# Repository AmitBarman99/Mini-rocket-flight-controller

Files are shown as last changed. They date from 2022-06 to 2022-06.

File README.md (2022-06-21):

# Mini-rocket-flight-controller
PCB board of mini rocket flight controller capable to store flight data

## The image of  this PCB board :point_down:

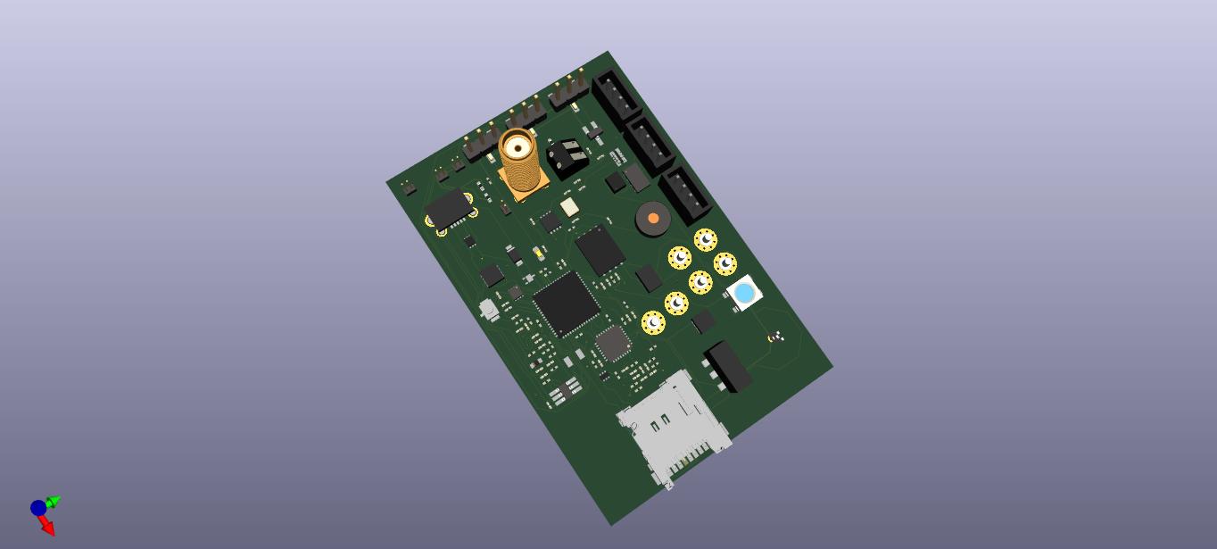
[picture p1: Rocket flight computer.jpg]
Rocket flight controller


### If you want to use this,follow these steps....

1. Download the [kicad](https://www.kicad.org/) and install it.
2. clone this repository

```bash
 git clone https://github.com/AmitBarman99/Mini-rocket-flight-controller.git 
```

3. Open the files or folder and customize them.
4. You can use [JLC pcb](https://jlcpcb.com/) for PCB fabrication

## [click here](https://amitbarman99.github.io/Mini-rocket-flight-controller/) to see the PCB board in 3D environment

 Be patient, it takes time to load
 
  I got help from this :point_right:[Repository](https://github.com/easyw/vrm360) to setup this 3D visualization. You can see it.

  ```javascript
  
  if (isAwasome){
        return true;
  }
  ```

  ## All the best

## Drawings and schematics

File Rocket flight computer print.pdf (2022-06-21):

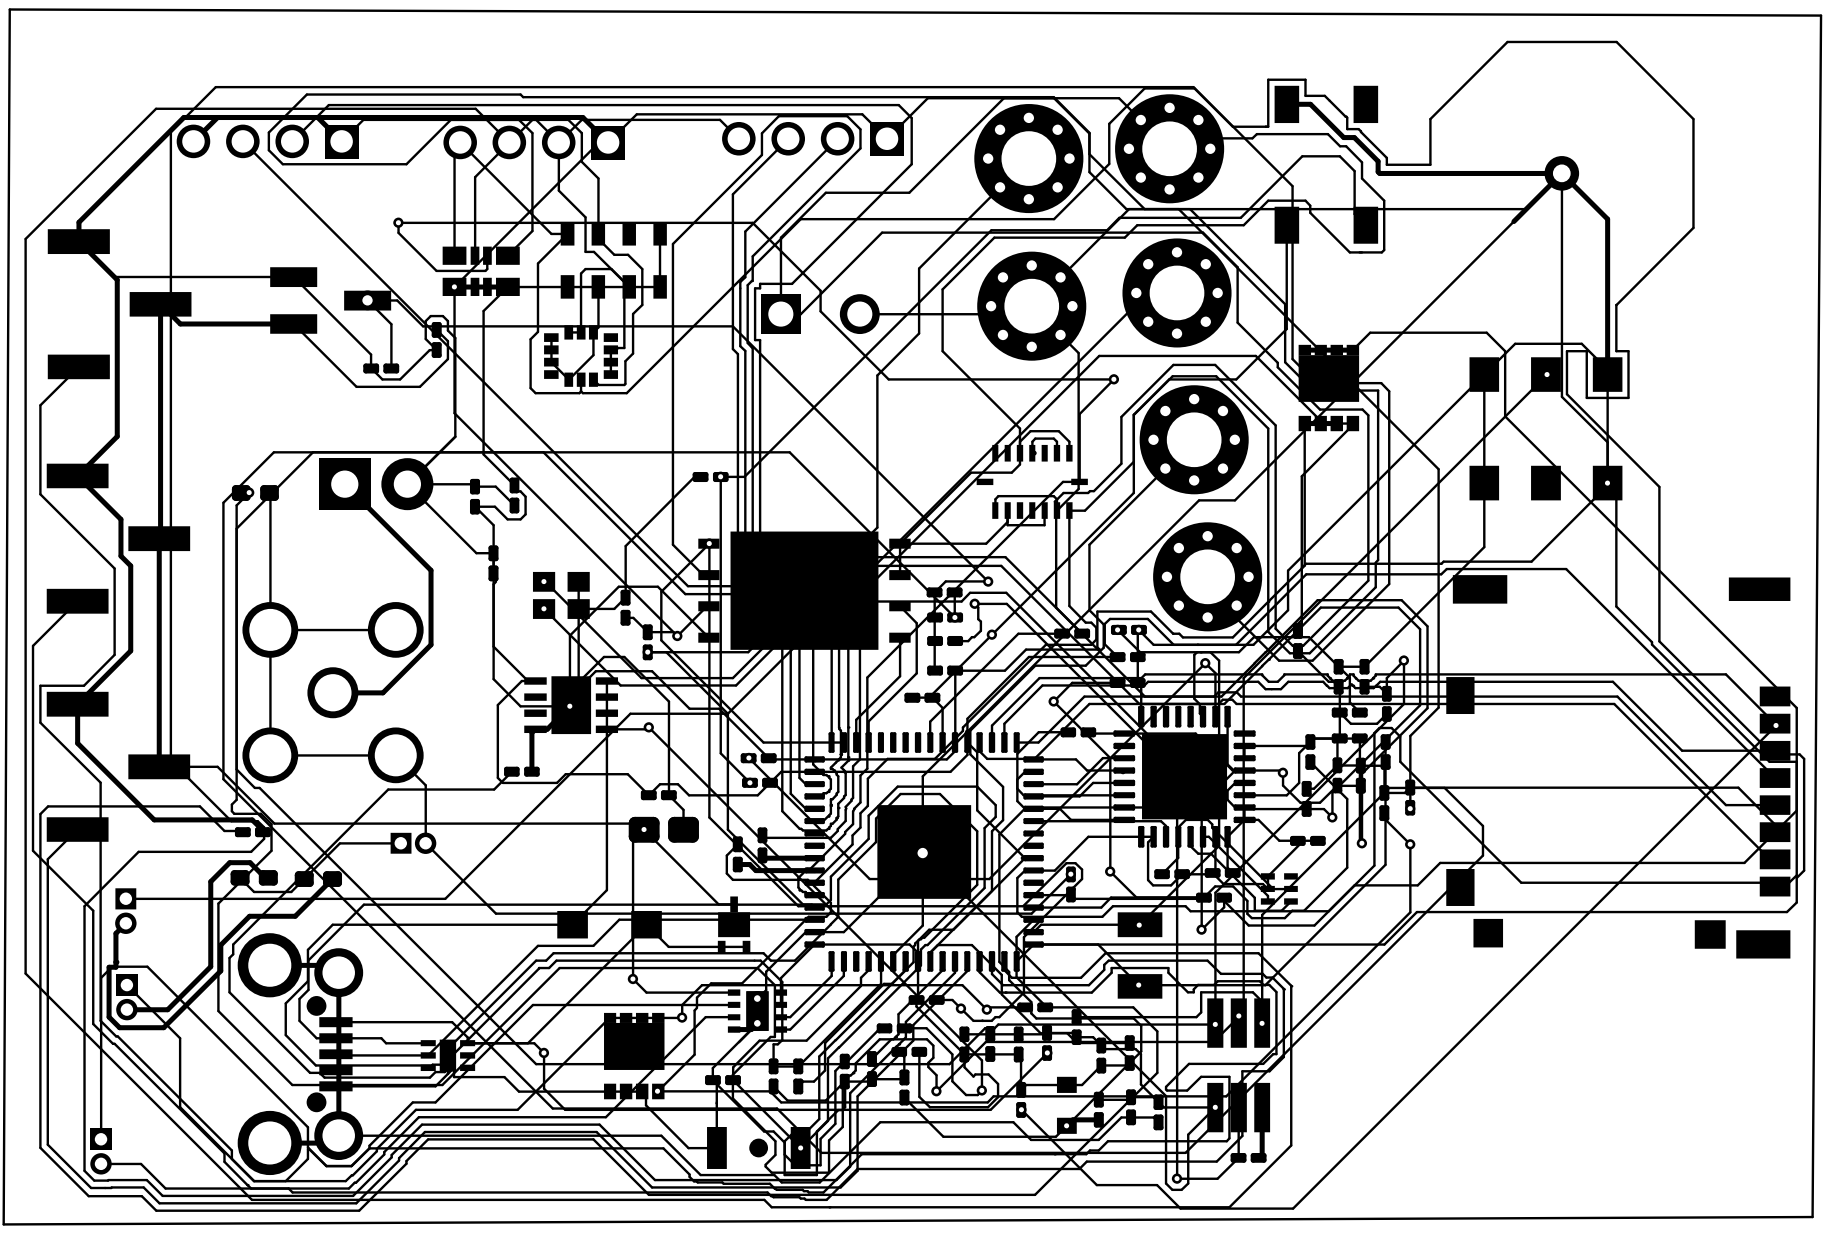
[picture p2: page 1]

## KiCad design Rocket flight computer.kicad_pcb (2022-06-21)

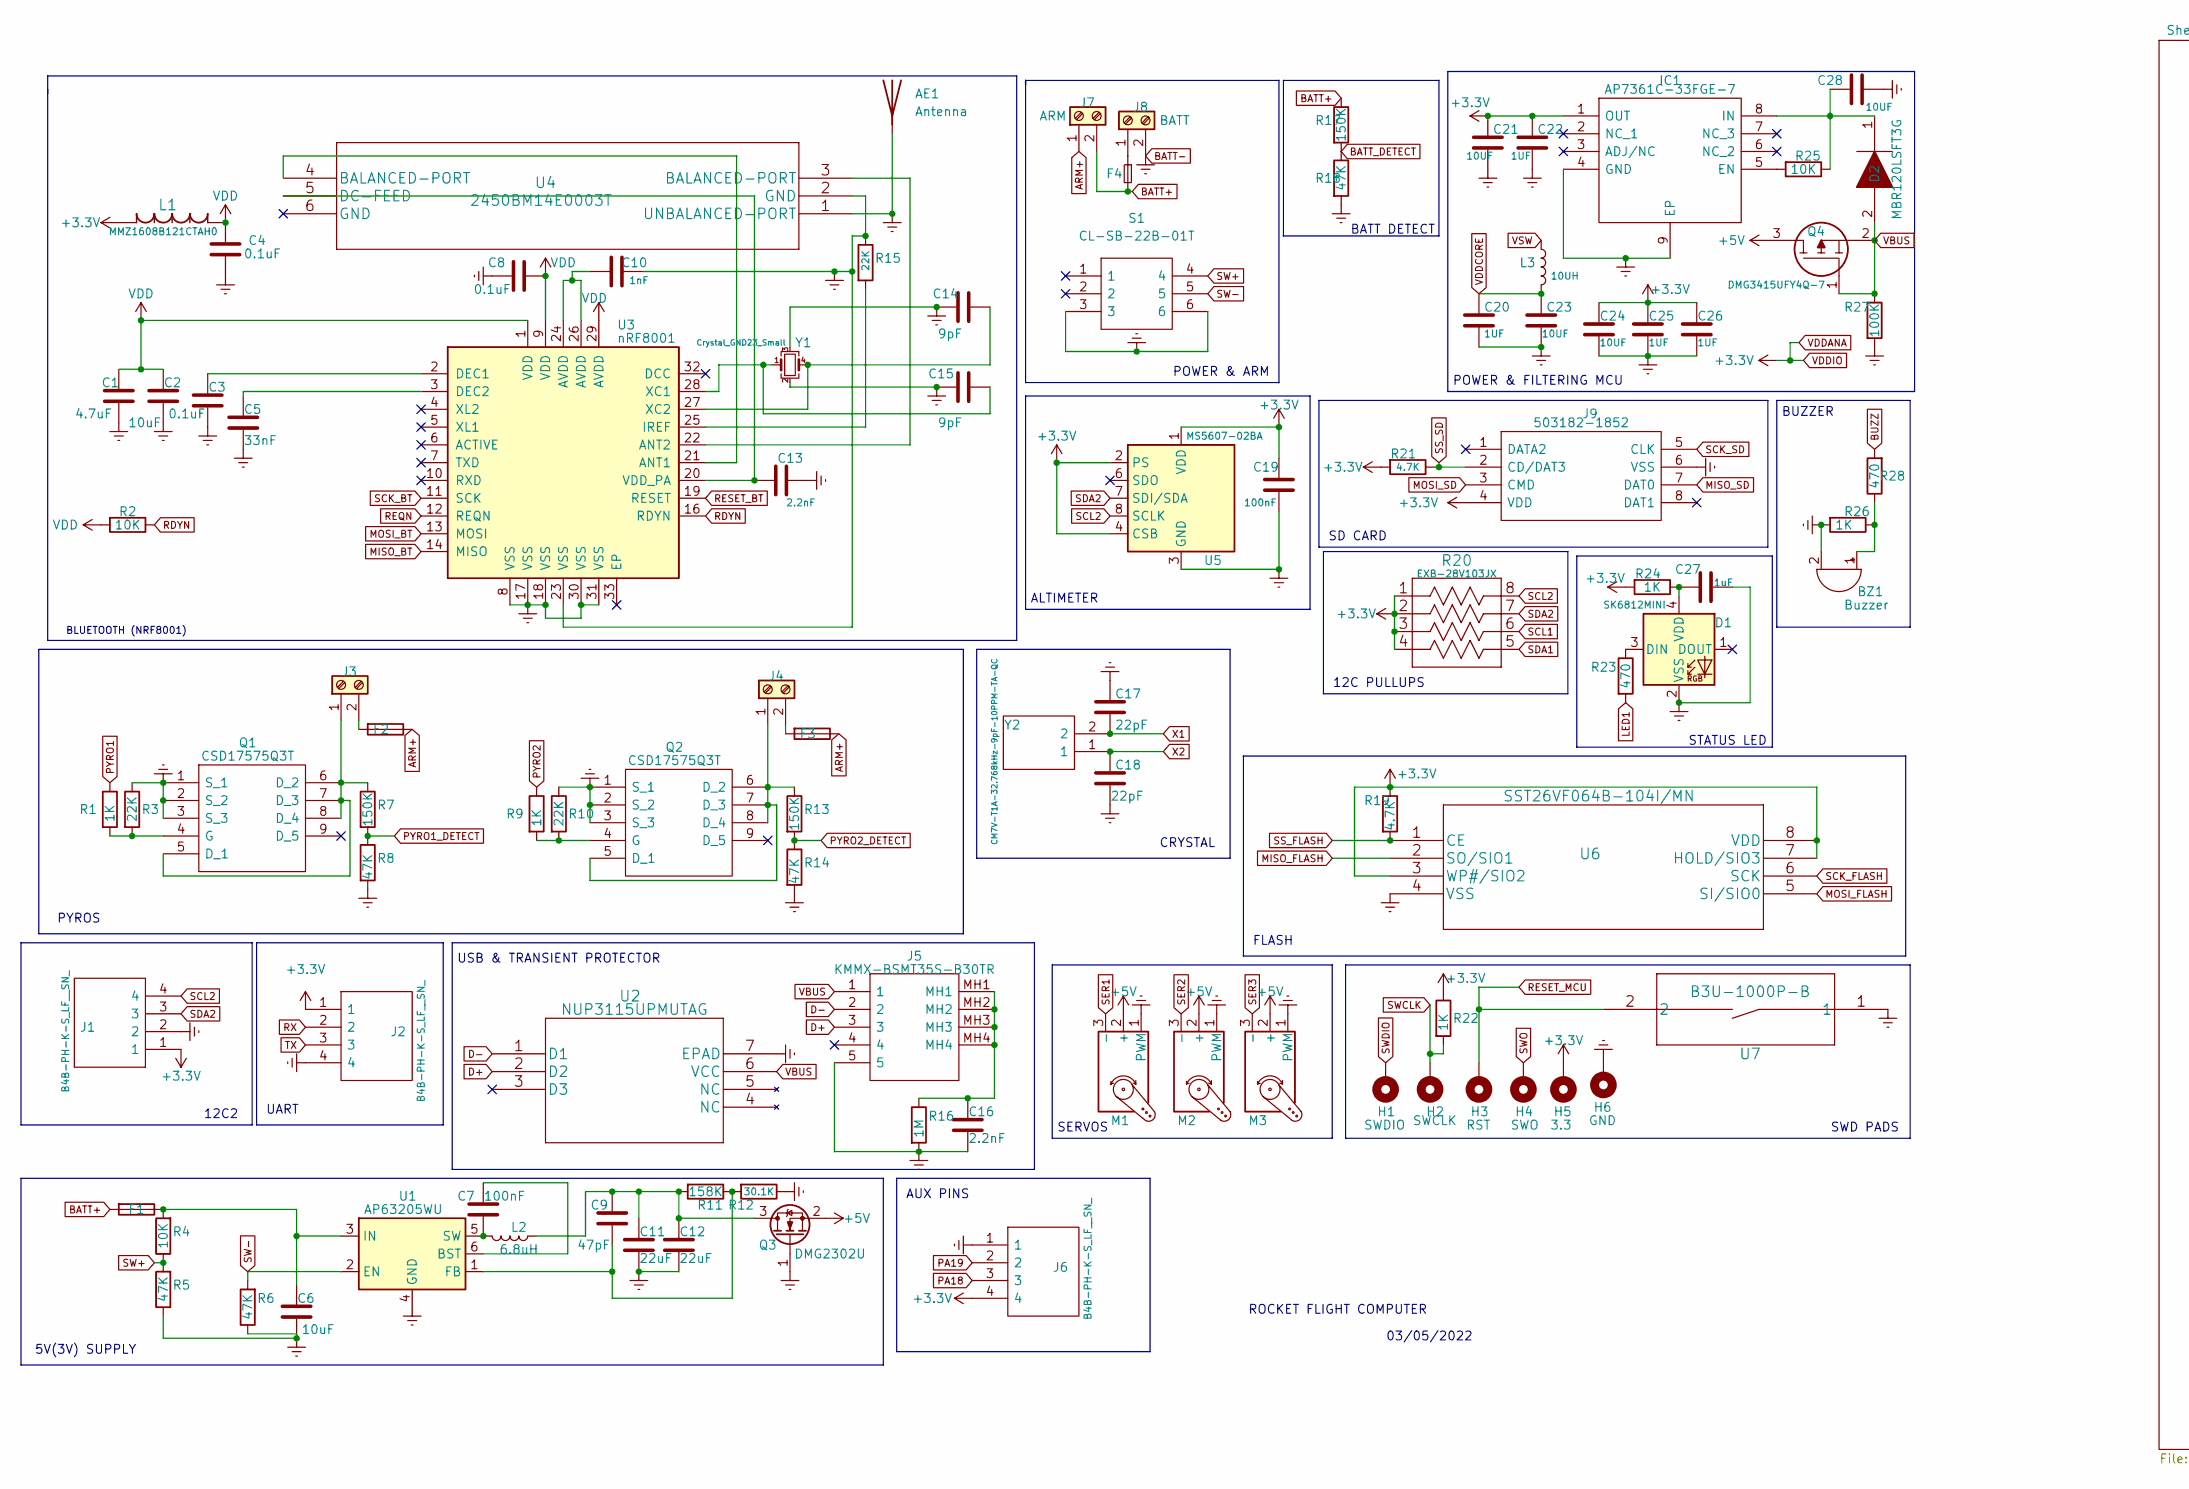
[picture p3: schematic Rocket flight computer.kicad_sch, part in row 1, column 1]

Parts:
AE1: Antenna; Banana_Jack_1Pin
BZ1: Buzzer; MagneticBuzzer_Kingstate_KCG0601
C1: 4.7uF; C_0201_0603Metric_Pad0.64x0.40mm_HandSolder
C2, C6: 10uF; C_0201_0603Metric_Pad0.64x0.40mm_HandSolder
C3, C4, C8: 0.1uF; C_0201_0603Metric_Pad0.64x0.40mm_HandSolder
C5: 33nF; C_0201_0603Metric_Pad0.64x0.40mm_HandSolder
C7, C19: 100nF; C_0201_0603Metric_Pad0.64x0.40mm_HandSolder
C9: 47pF; C_0201_0603Metric_Pad0.64x0.40mm_HandSolder
C10: 1nF; C_0201_0603Metric_Pad0.64x0.40mm_HandSolder
C11, C12: 22uF; C_0201_0603Metric_Pad0.64x0.40mm_HandSolder
C13, C16: 2.2nF; C_0201_0603Metric_Pad0.64x0.40mm_HandSolder
C14, C15: 9pF; C_0201_0603Metric_Pad0.64x0.40mm_HandSolder
C17, C18: 22pF; C_0201_0603Metric_Pad0.64x0.40mm_HandSolder
C20, C22, C25, C26: 1UF; C_0201_0603Metric_Pad0.64x0.40mm_HandSolder
C21, C23, C24, C28: 10UF; C_0201_0603Metric_Pad0.64x0.40mm_HandSolder
C27: 1uF; C_0201_0603Metric_Pad0.64x0.40mm_HandSolder
D1: SK6812MINI; LED_SK6812_PLCC4_5.0x5.0mm_P3.2mm
D2: MBR120LSFT3G; Manufacturer_Part_Number MBR120LSFT3G; Mouser Part Number 863-MBR120LSFT3G
F1, F2, F3: Fuse; Fuse_0402_1005Metric_Pad0.77x0.64mm_HandSolder
F4: Fuse_Small; SMA_Amphenol_132134-11_Vertical
H1: SWDIO; MountingHole_2.2mm_M2_Pad_Via
H2: SWCLK; MountingHole_2.2mm_M2_Pad_Via
H3: RST; MountingHole_2.2mm_M2_Pad_Via
H4: SWO; MountingHole_2.2mm_M2_Pad_Via
H5: 3.3; MountingHole_2.2mm_M2_Pad_Via
H6: GND; MountingHole_2.2mm_M2_Pad_Via
IC1: AP7361C-33FGE-7; Manufacturer_Part_Number AP7361C-33FGE-7; Mouser Part Number 621-AP7361C-33FGE-7
J1, J2, J6: B4B-PH-K-S_LF__SN_; B4B-PH-K-SLF_SN; Manufacturer_Part_Number B4B-PH-K-S(LF)(SN)
J3, J4, J7: ARM; Banana_Jack_2Pin
J5: KMMX-BSMT35S-B30TR; KMMXBSMT35SB30TR; Manufacturer_Part_Number KMMX-BSMT35S-B30TR; Mouser Part Number 806-KMMXBSMT35SB30TR
J8: BATT; TerminalBlock_TE_282834-2_1x02_P2.54mm_Horizontal
J9: 503182-1852; 5031821852; Manufacturer_Part_Number 503182-1852; Mouser Part Number 538-503182-1852
L1: MMZ1608B121CTAH0
L2: 6.8uH; L_0201_0603Metric_Pad0.64x0.40mm_HandSolder
L3: 10UH; L_0201_0603Metric_Pad0.64x0.40mm_HandSolder
M1, M2, M3: Motor_Servo; PinHeader_1x03_P2.54mm_Vertical_SMD_Pin1Left
Q1, Q2: CSD17575Q3T; Manufacturer_Part_Number CSD17575Q3T; Mouser Part Number 595-CSD17575Q3T
Q3: DMG2302U; SOT-23_Handsoldering
Q4: DMG3415UFY4Q-7; DMG3415UFY47; Manufacturer_Part_Number DMG3415UFY4Q-7; Mouser Part Number 621-DMG3415UFY4Q-7
R1, R9, R22, R24, R26: 1K; R_0201_0603Metric_Pad0.64x0.40mm_HandSolder
R2, R4, R25: 10K; R_0201_0603Metric_Pad0.64x0.40mm_HandSolder
R3, R10, R15: 22K; R_0201_0603Metric_Pad0.64x0.40mm_HandSolder
R5, R6, R8, R14, R18: 47K; R_0201_0603Metric_Pad0.64x0.40mm_HandSolder
R7, R13, R17: 150K; R_0201_0603Metric_Pad0.64x0.40mm_HandSolder
R11: 158K; R_0201_0603Metric_Pad0.64x0.40mm_HandSolder
R12: 30.1K; R_0201_0603Metric_Pad0.64x0.40mm_HandSolder
R16: 1M; R_0201_0603Metric_Pad0.64x0.40mm_HandSolder
R19, R21: 4.7K; R_0201_0603Metric_Pad0.64x0.40mm_HandSolder
R20: EXB-28V103JX
R23, R28: 470; R_0201_0603Metric_Pad0.64x0.40mm_HandSolder
R27: 100K; R_0201_0603Metric_Pad0.64x0.40mm_HandSolder
S1: CL-SB-22B-01T; CLSB22B01T; Manufacturer_Part_Number CL-SB-22B-01T
U1: AP63205WU; TSOT-23-6_HandSoldering
U2: NUP3115UPMUTAG
U3: nRF8001; QFN-32-1EP_5x5mm_P0.5mm_EP3.45x3.45mm
U4: 2450BM14E0003T
U5: MS5607-02BA; LGA-8_3x5mm_P1.25mm
U6: SST26VF064B-104I/MN; SST26VF064B-104IMN
U7: B3U-1000P-B
Y1: Crystal_GND23_Small; Crystal_SMD_2016-4Pin_2.0x1.6mm
Y2: CM7V-T1A-32.768kHz-9pF-10PPM-TA-QC; CM7V32768TBQA020; Manufacturer_Part_Number CM7V-T1A-32.768kHz-9pF-10PPM-TA-QC; Mouser Part Number 428-201565-MG01

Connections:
+5V: M1.2 (+), M2.2 (+), M3.2 (+), Q3.2 (S), Q4.3; also elsewhere on the board
ARM+: F2.1, F3.1, J7.1
BATT+: F1.2, F4.2, J7.2, R17.1
BATT-: AE1.1 (A), BZ1.2 (+), C1.2, C2.2, C3.2, C4.2, C5.2, C6.2, C8.2, C10.1, C11.2, C12.2, C13.1, C14.2, C15.2, C16.2, C17.1, C18.2, C19.2, C20.2, C21.2, C22.2, C23.2, C24.2, C25.2, C26.2, C27.1, C28.1, D1.2 (VSS), H6.1, IC1.4 (GND), IC1.9 (EP), J1.2, J2.4, J5.5, J6.1, J8.2, J9.6 (VSS), M1.1 (PWM), M2.1 (PWM), M3.1 (PWM), Q1.1 (S_1), Q1.2 (S_2), Q1.3 (S_3), Q2.1 (S_1), Q2.2 (S_2), Q2.3 (S_3), Q3.1 (G), R3.1, R5.1, R6.1, R8.2, R10.1, R12.1, R14.2, R15.1, R16.2, R18.2, R26.2, R27.2, S1.3, S1.6, U1.4 (GND), U2.7 (EPAD), U3.8 (VSS), U3.17 (VSS), U3.18 (VSS), U3.23 (VSS), U3.30 (VSS), U3.31 (VSS), U4.1 (UNBALANCED-PORT), U4.2 (GND), U5.3 (GND), U6.4 (VSS), U7.1, Y1.2, Y1.3; also elsewhere on the board
BATT_DETECT: R17.2, R18.1; also elsewhere on the board
BUZZ: R28.2; also elsewhere on the board
D+: J5.3, U2.2 (D2); also elsewhere on the board
D-: J5.2, U2.1 (D1); also elsewhere on the board
LED1: R23.2; also elsewhere on the board
MISO_BT: U3.14 (MISO); also elsewhere on the board
MISO_FLASH: U6.2 (SO/SIO1); also elsewhere on the board
MISO_SD: J9.7 (DAT0); also elsewhere on the board
MOSI_BT: U3.13 (MOSI); also elsewhere on the board
MOSI_FLASH: U6.5 (SI/SIO0); also elsewhere on the board
MOSI_SD: J9.3 (CMD); also elsewhere on the board
unnamed: BZ1.1 (-), R26.1, R28.1
unnamed: C3.1, U3.2 (DEC1)
unnamed: C5.1, U3.3 (DEC2)
unnamed: C6.1, F1.1, R4.2, U1.3 (IN)
unnamed: C7.1, U1.6 (BST)
unnamed: C7.2, L2.2, U1.5 (SW)
unnamed: C9.2, R11.1, R12.2, U1.1 (FB)
unnamed: C10.2, U3.24 (AVDD), U3.26 (AVDD)
unnamed: C9.1, C11.1, C12.1, L2.1, Q3.3 (D), R11.2
unnamed: C13.2, U3.20 (VDD_PA), U4.5 (DC-FEED)
unnamed: C14.1, U3.27 (XC2), Y1.4
unnamed: C15.1, U3.28 (XC1), Y1.1
unnamed: C16.1, J5.MH1, J5.MH2, J5.MH3, J5.MH4, R16.1
unnamed: C27.2, D1.4 (VDD), R24.1
unnamed: C28.2, D2.1, IC1.8 (IN), R25.1
unnamed: D1.3 (DIN), R23.1
unnamed: F2.2, J3.2
unnamed: F3.2, J4.2
unnamed: F4.1, J8.1
unnamed: IC1.5 (EN), R25.2
unnamed: J3.1, Q1.5 (D_1), Q1.6 (D_2), Q1.7 (D_3), Q1.8 (D_4), R7.1
unnamed: J4.1, Q2.5 (D_1), Q2.6 (D_2), Q2.7 (D_3), Q2.8 (D_4), R13.1
unnamed: Q1.4 (G), R1.2, R3.2
unnamed: Q2.4 (G), R9.2, R10.2
unnamed: R15.2, U3.25 (IREF)
unnamed: U3.21 (ANT1), U4.4 (BALANCED-PORT)
unnamed: U3.22 (ANT2), U4.3 (BALANCED-PORT)
PA18: J6.3; also elsewhere on the board
PA19: J6.2; also elsewhere on the board
PYRO1: R1.1; also elsewhere on the board
PYRO1_DETECT: R7.2, R8.1; also elsewhere on the board
PYRO2: R9.1; also elsewhere on the board
PYRO2_DETECT: R13.2, R14.1; also elsewhere on the board
RDYN: R2.1, U3.16 (RDYN); also elsewhere on the board
REQN: U3.12 (REQN); also elsewhere on the board
RESET_BT: U3.19 (RESET); also elsewhere on the board
RESET_MCU: H3.1, U7.2; also elsewhere on the board
RX: J2.2; also elsewhere on the board
SCK_BT: U3.11 (SCK); also elsewhere on the board
SCK_FLASH: U6.6 (SCK); also elsewhere on the board
SCK_SD: J9.5 (CLK); also elsewhere on the board
SCL1: R20.6; also elsewhere on the board
SCL2: J1.4, R20.8, U5.8 (SCLK); also elsewhere on the board
SDA1: R20.5; also elsewhere on the board
SDA2: J1.3, R20.7, U5.7 (SDI/SDA); also elsewhere on the board
SER1: M1.3 (-); also elsewhere on the board
SER2: M2.3 (-); also elsewhere on the board
SER3: M3.3 (-); also elsewhere on the board
SS_FLASH: R19.2, U6.1 (CE); also elsewhere on the board
SS_SD: J9.2 (CD/DAT3), R21.1; also elsewhere on the board
SW+: R4.1, R5.2, S1.4
SW-: R6.2, S1.5, U1.2 (EN)
SWCLK: H2.1, R22.2; also elsewhere on the board
SWDIO: H1.1; also elsewhere on the board
SWO: H4.1; also elsewhere on the board
TX: J2.3; also elsewhere on the board
VBUS: D2.2, J5.1, Q4.1, Q4.2, R27.1, U2.6 (VCC)
VDD: C1.1, C2.1, C4.1, C8.1, L1.1, R2.2, U3.1 (VDD), U3.9 (VDD), U3.29 (AVDD)
VDDANA: C19.1, C21.1, C22.1, C24.1, C25.1, C26.1, H5.1, IC1.1 (OUT), J1.1, J2.1, J6.4, J9.4 (VDD), L1.2, R19.1, R20.1, R20.2, R20.3, R20.4, R21.2, R22.1, R24.2, U5.1 (VDD), U5.2 (PS), U5.4 (CSB), U5.5 (CSB), U6.3 (WP#/SIO2), U6.7 (HOLD/SIO3), U6.8 (VDD); also elsewhere on the board
VDDCORE: C20.1, C23.1, L3.2; also elsewhere on the board
VSW: L3.1; also elsewhere on the board
X1: C17.2, Y2.2; also elsewhere on the board
X2: C18.1, Y2.1; also elsewhere on the board

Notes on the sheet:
POWER & ARM
AUX PINS
FLASH
USB & TRANSIENT PROTECTOR
SWD PADS
BATT DETECT
BUZZER
SD CARD
PYROS
UART
5V(3V) SUPPLY
STATUS LED
BLUETOOTH (NRF8001)
03/05/2022
ROCKET FLIGHT COMPUTER
SERVOS
CRYSTAL
ALTIMETER
12C2
12C PULLUPS
POWER & FILTERING MCU

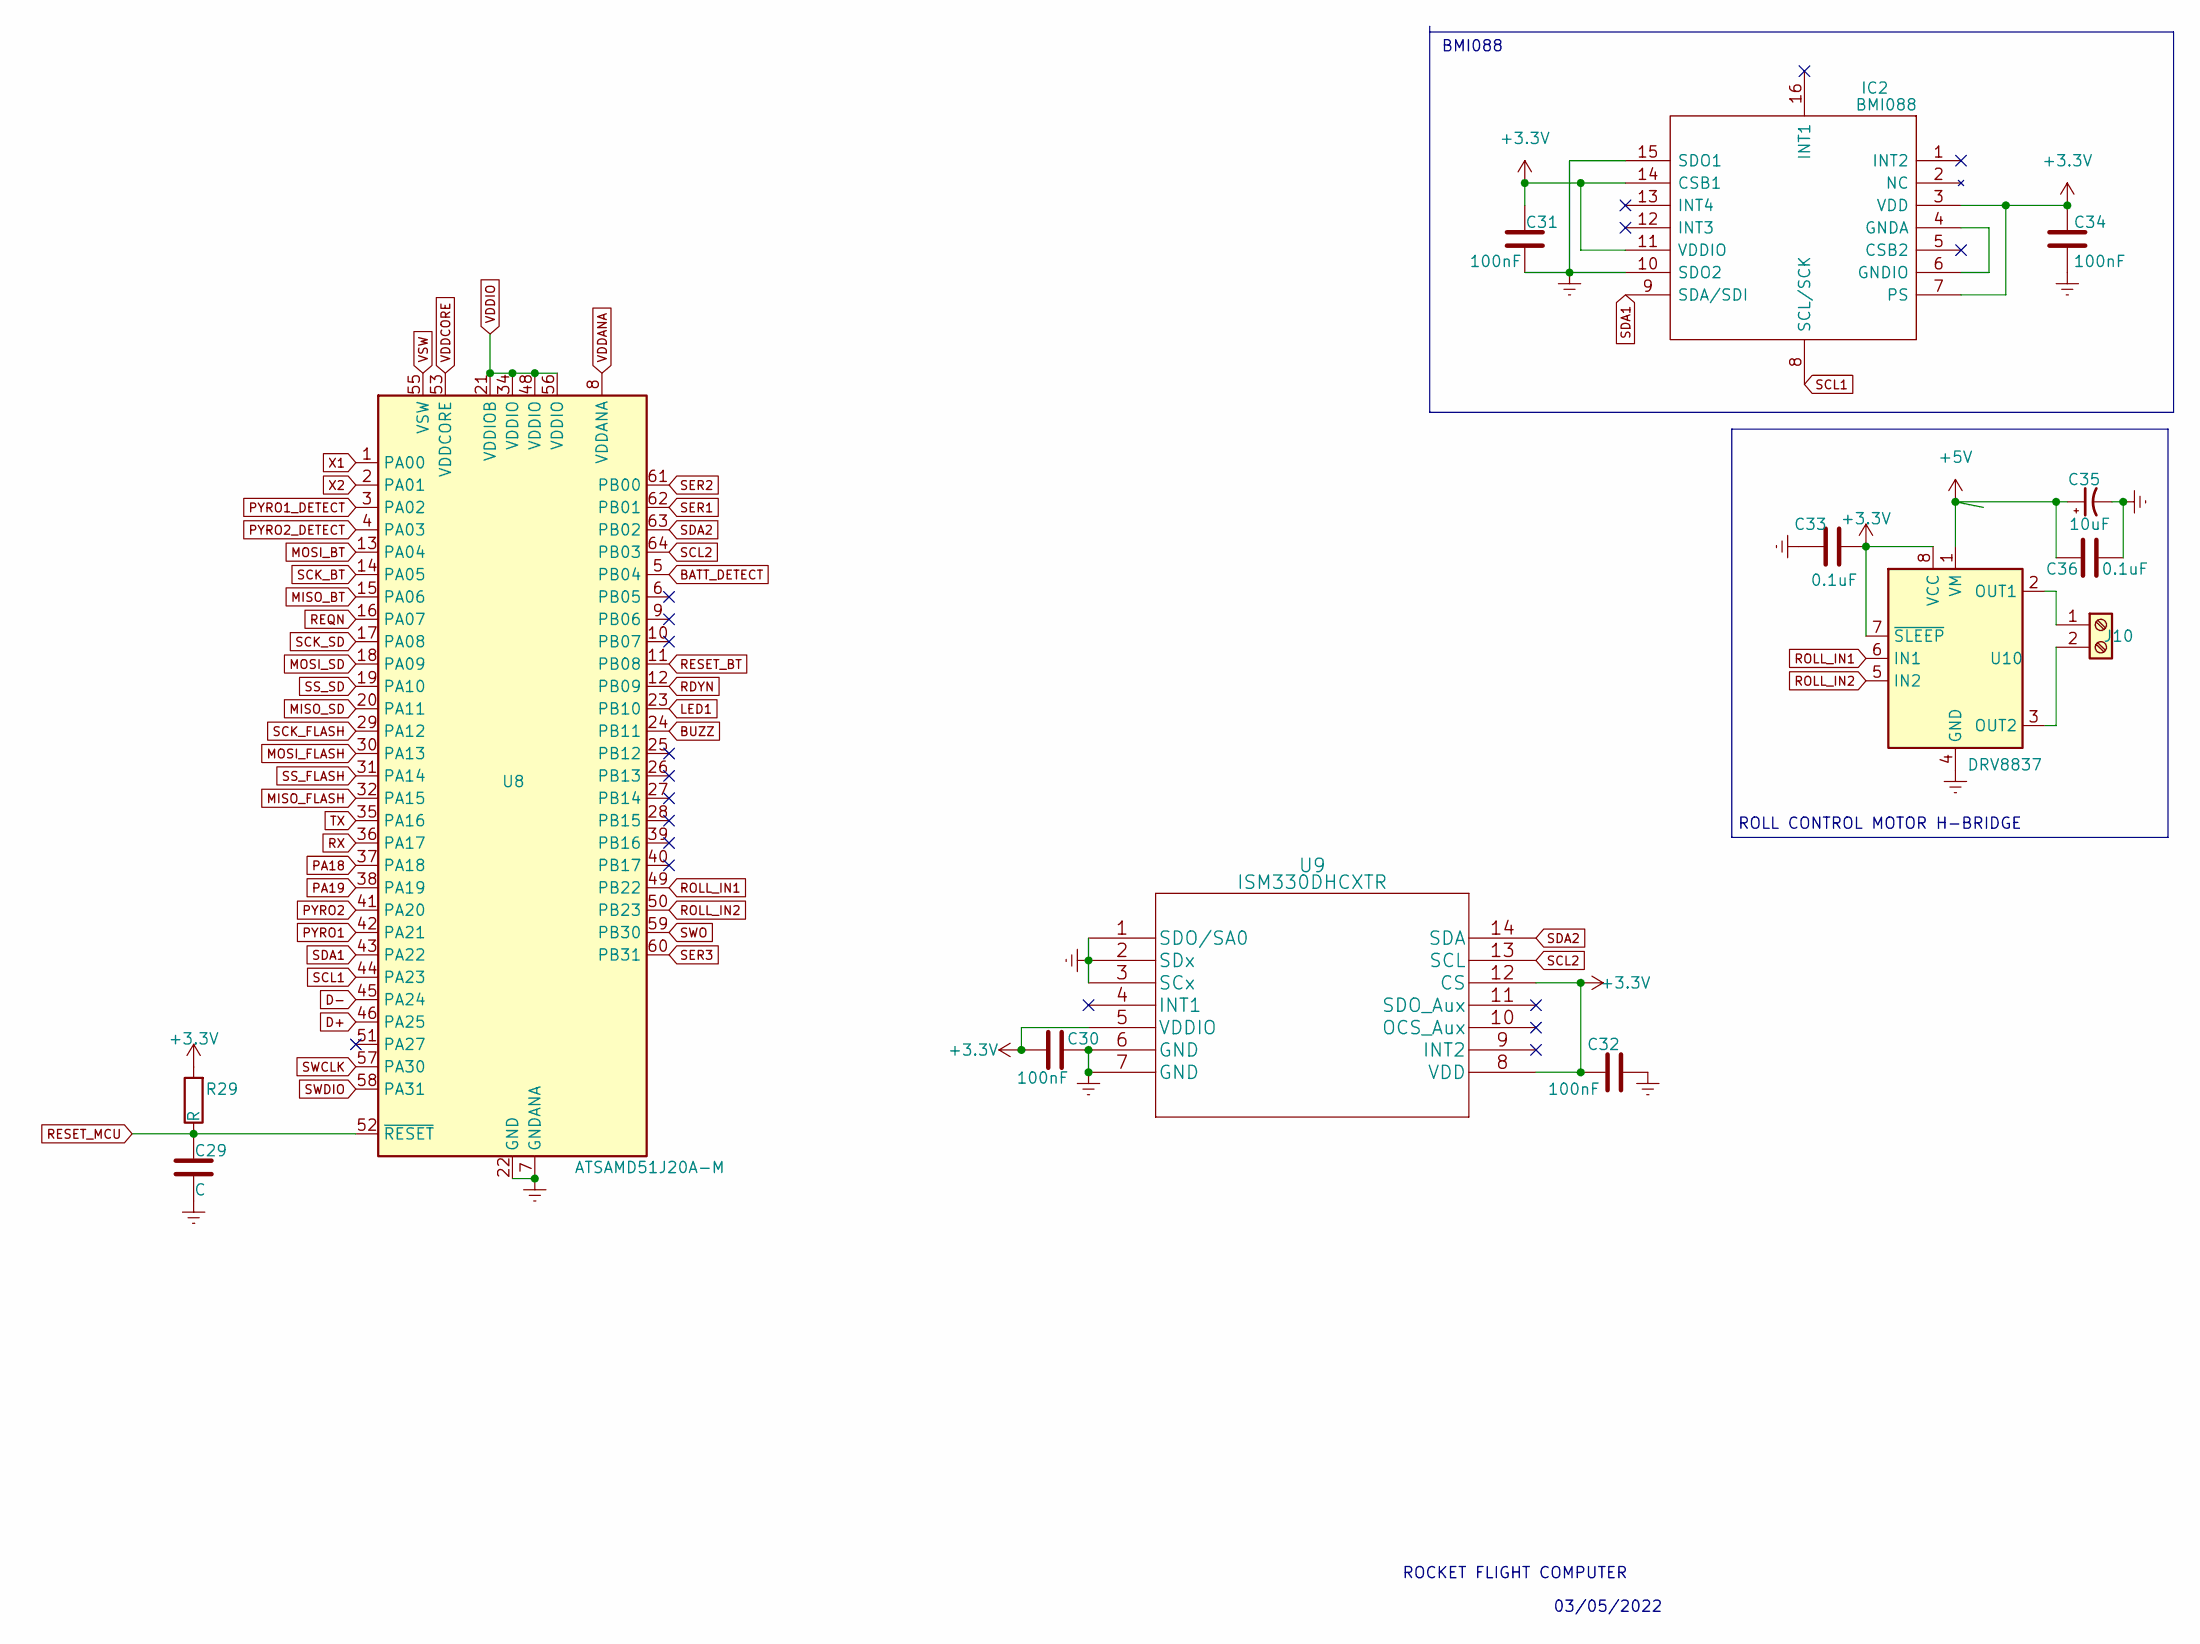
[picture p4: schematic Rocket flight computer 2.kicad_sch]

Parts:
C29: C; C_0201_0603Metric_Pad0.64x0.40mm_HandSolder
C30, C31, C32, C34: 100nF; C_0201_0603Metric_Pad0.64x0.40mm_HandSolder
C33, C36: 0.1uF; C_0201_0603Metric_Pad0.64x0.40mm_HandSolder
C35: 10uF; CP_EIA-1608-08_AVX-J_Pad1.25x1.05mm_HandSolder
IC2: BMI088; Manufacturer_Part_Number BMI088; Mouser Part Number 262-BMI088
J10: ARM; Banana_Jack_2Pin
R29: R; R_0201_0603Metric_Pad0.64x0.40mm_HandSolder
U8: ATSAMD51J20A-M; QFN-64-1EP_9x9mm_P0.5mm_EP3.8x3.8mm
U9: ISM330DHCXTR
U10: DRV8837; WSON-8-1EP_2x2mm_P0.5mm_EP0.9x1.6mm_ThermalVias

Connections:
+5V: C35.1, C36.2, U10.1 (VM); also elsewhere on the board
BATT-: C29.1, C30.1, C31.2, C32.1, C33.2, C34.2, C35.2, C36.1, IC2.10 (SDO2), IC2.15 (SDO1), U8.7 (GNDANA), U8.22 (GND), U8.33 (GND), U8.47 (GND), U8.54 (GND), U8.65 (GND), U9.1 (SDO/SA0), U9.2 (SDx), U9.3 (SCx), U9.6 (GND), U9.7 (GND), U10.4 (GND), U10.9 (GND); also elsewhere on the board
BATT_DETECT: U8.5 (PB04); also elsewhere on the board
BUZZ: U8.24 (PB11); also elsewhere on the board
D+: U8.46 (PA25); also elsewhere on the board
D-: U8.45 (PA24); also elsewhere on the board
LED1: U8.23 (PB10); also elsewhere on the board
MISO_BT: U8.15 (PA06); also elsewhere on the board
MISO_FLASH: U8.32 (PA15); also elsewhere on the board
MISO_SD: U8.20 (PA11); also elsewhere on the board
MOSI_BT: U8.13 (PA04); also elsewhere on the board
MOSI_FLASH: U8.30 (PA13); also elsewhere on the board
MOSI_SD: U8.18 (PA09); also elsewhere on the board
unnamed: IC2.4 (GNDA), IC2.6 (GNDIO)
unnamed: J10.1, U10.2 (OUT1)
unnamed: J10.2, U10.3 (OUT2)
PA18: U8.37 (PA18); also elsewhere on the board
PA19: U8.38 (PA19); also elsewhere on the board
PYRO1: U8.42 (PA21); also elsewhere on the board
PYRO1_DETECT: U8.3 (PA02); also elsewhere on the board
PYRO2: U8.41 (PA20); also elsewhere on the board
PYRO2_DETECT: U8.4 (PA03); also elsewhere on the board
RDYN: U8.12 (PB09); also elsewhere on the board
REQN: U8.16 (PA07); also elsewhere on the board
RESET_BT: U8.11 (PB08); also elsewhere on the board
RESET_MCU: C29.2, R29.1, U8.52 (~RESET); also elsewhere on the board
ROLL_IN1: U8.49 (PB22), U10.6 (IN1)
ROLL_IN2: U8.50 (PB23), U10.5 (IN2)
RX: U8.36 (PA17); also elsewhere on the board
SCK_BT: U8.14 (PA05); also elsewhere on the board
SCK_FLASH: U8.29 (PA12); also elsewhere on the board
SCK_SD: U8.17 (PA08); also elsewhere on the board
SCL1: IC2.8 (SCL/SCK), U8.44 (PA23); also elsewhere on the board
SCL2: U8.64 (PB03), U9.13 (SCL); also elsewhere on the board
SDA1: IC2.9 (SDA/SDI), U8.43 (PA22); also elsewhere on the board
SDA2: U8.63 (PB02), U9.14 (SDA); also elsewhere on the board
SER1: U8.62 (PB01); also elsewhere on the board
SER2: U8.61 (PB00); also elsewhere on the board
SER3: U8.60 (PB31); also elsewhere on the board
SS_FLASH: U8.31 (PA14); also elsewhere on the board
SS_SD: U8.19 (PA10); also elsewhere on the board
SWCLK: U8.57 (PA30); also elsewhere on the board
SWDIO: U8.58 (PA31); also elsewhere on the board
SWO: U8.59 (PB30); also elsewhere on the board
TX: U8.35 (PA16); also elsewhere on the board
VDDANA: C30.2, C31.1, C32.2, C33.1, C34.1, IC2.3 (VDD), IC2.7 (PS), IC2.11 (VDDIO), IC2.14 (CSB1), R29.2, U8.8 (VDDANA), U8.21 (VDDIOB), U8.34 (VDDIO), U8.48 (VDDIO), U8.56 (VDDIO), U9.5 (VDDIO), U9.8 (VDD), U9.12 (CS), U10.7 (~SLEEP), U10.8 (VCC); also elsewhere on the board
VDDCORE: U8.53 (VDDCORE); also elsewhere on the board
VSW: U8.55 (VSW); also elsewhere on the board
X1: U8.1 (PA00); also elsewhere on the board
X2: U8.2 (PA01); also elsewhere on the board

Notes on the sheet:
03/05/2022
BMI088
ROLL CONTROL MOTOR H-BRIDGE
ROCKET FLIGHT COMPUTER

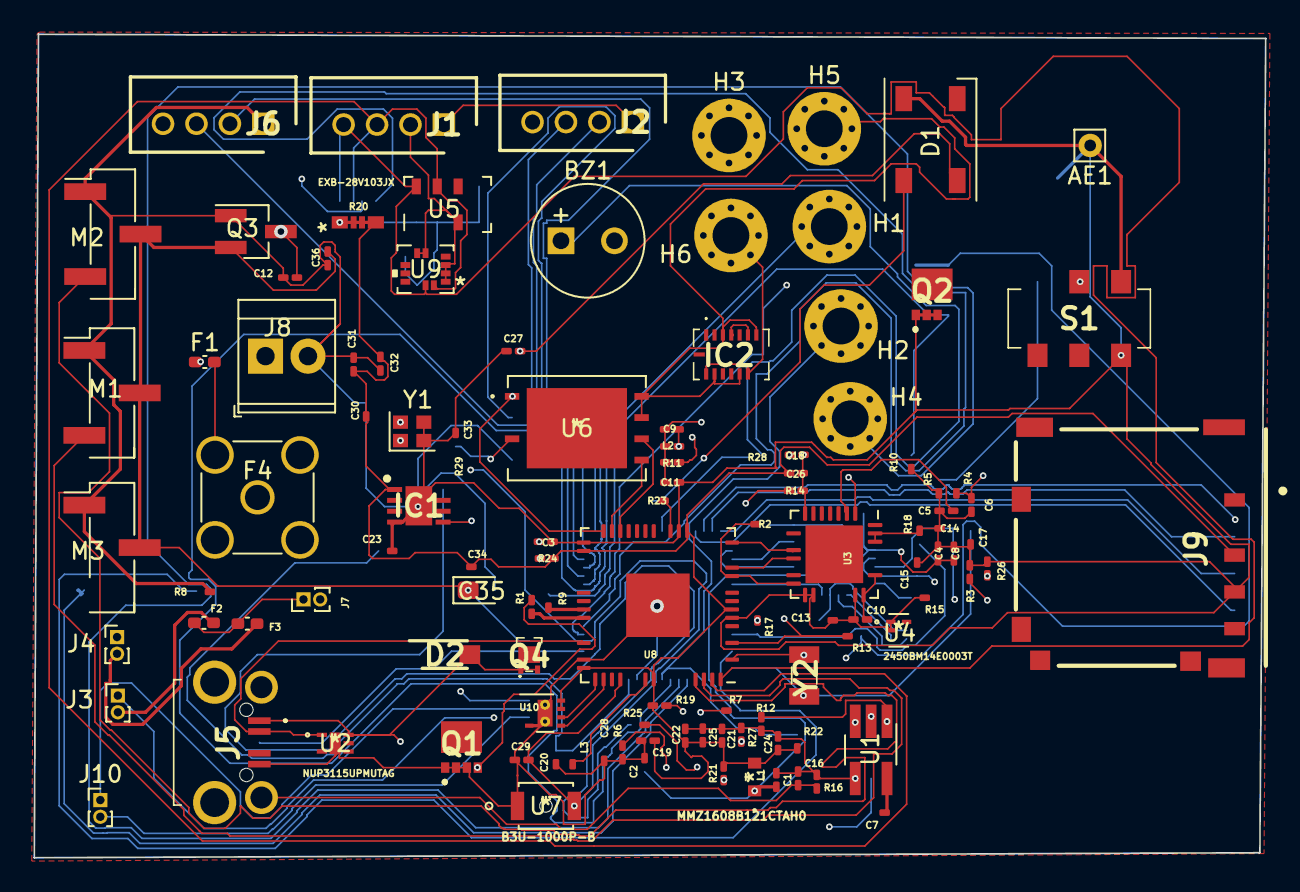
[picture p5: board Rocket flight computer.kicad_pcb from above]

Board: 4 copper layers, 73.6 x 49.2 mm, 114 parts (0 on the bottom side), 83 nets.

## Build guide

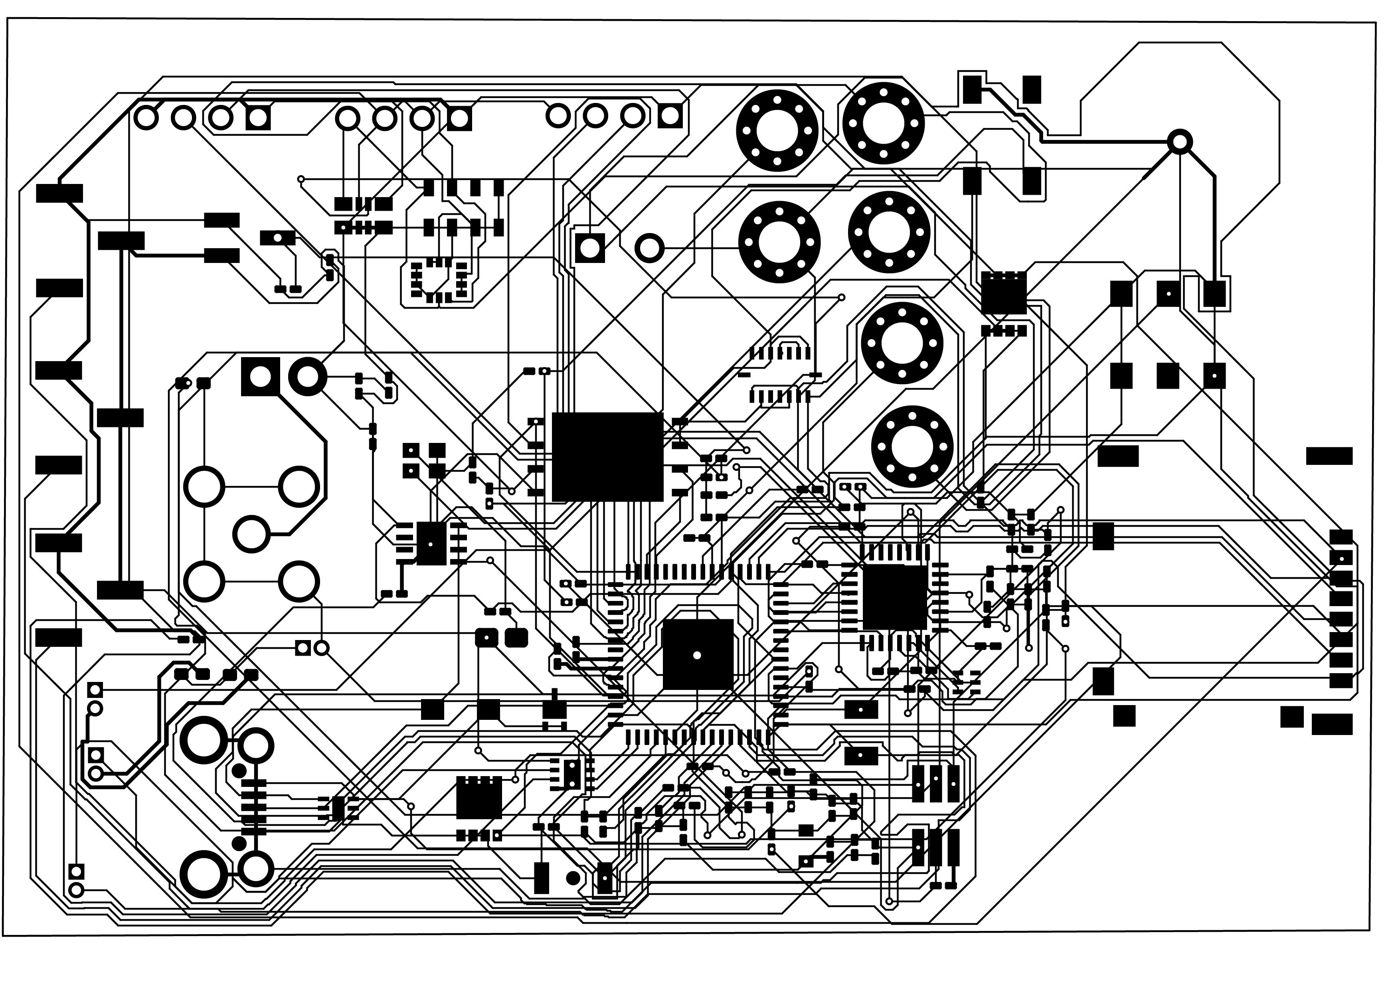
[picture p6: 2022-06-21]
Rocket flight computer print.jpg

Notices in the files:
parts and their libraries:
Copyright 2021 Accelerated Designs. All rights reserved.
